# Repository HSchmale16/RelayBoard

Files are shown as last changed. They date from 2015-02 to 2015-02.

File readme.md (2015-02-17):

# Relay Board

**THESE DESIGNS ARE NO WHERE NEAR DONE.**

These are designs for a 32 Channel Relay Board that can be driven with
small microcontrollers, such as the Arduino and the BeagleBone.
The included designs are for KiCad.

These designs are provided with **NO WARRANTY WHATSOEVER**. No liability
is assumed by the designer of these circuits.

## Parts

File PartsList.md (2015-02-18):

# Parts List

* Relays - SPDT
    * TE Connectivity 1461069-5
    * MFR Part No. 1461069-5
    * http://www.digikey.com/product-detail/en/1461069-5/PB1321-ND/3318145
    * $ 1.0156 @ QTY 32
* Diode - 1N4007
    * http://www.digikey.com/product-detail/en/1N4007-TP/1N4007-TPMSCT-ND/773694
    * $ 0.0900 @ QTY 32
* Terminal Block - 3 Connections Screw Type
    * http://www.digikey.com/product-detail/en/OSTTE030161/ED2636-ND/614585
    * $ 0.6000 @ QTY 32
* Transistors - 2N2222
    * http://www.digikey.com/product-detail/en/2N2222/2N2222CS-ND/4806844
    * $ 1.6000 @ QTY 32
* Resistors - 1K ohms
    * http://www.digikey.com/product-detail/en/CFR-25JB-52-1K/1.0KQBK-ND/96
    * $0.04400 @ QTY 32
* Copper Clad Board - 12" x 12"
    * http://www.digikey.com/product-detail/en/555/473-1007-ND/559707
    * $ 22.4200 @ QTY 01

# Notes
Free Shipping: http://dangerousprototypes.com/2011/05/19/free-digikey-shipping-tip/

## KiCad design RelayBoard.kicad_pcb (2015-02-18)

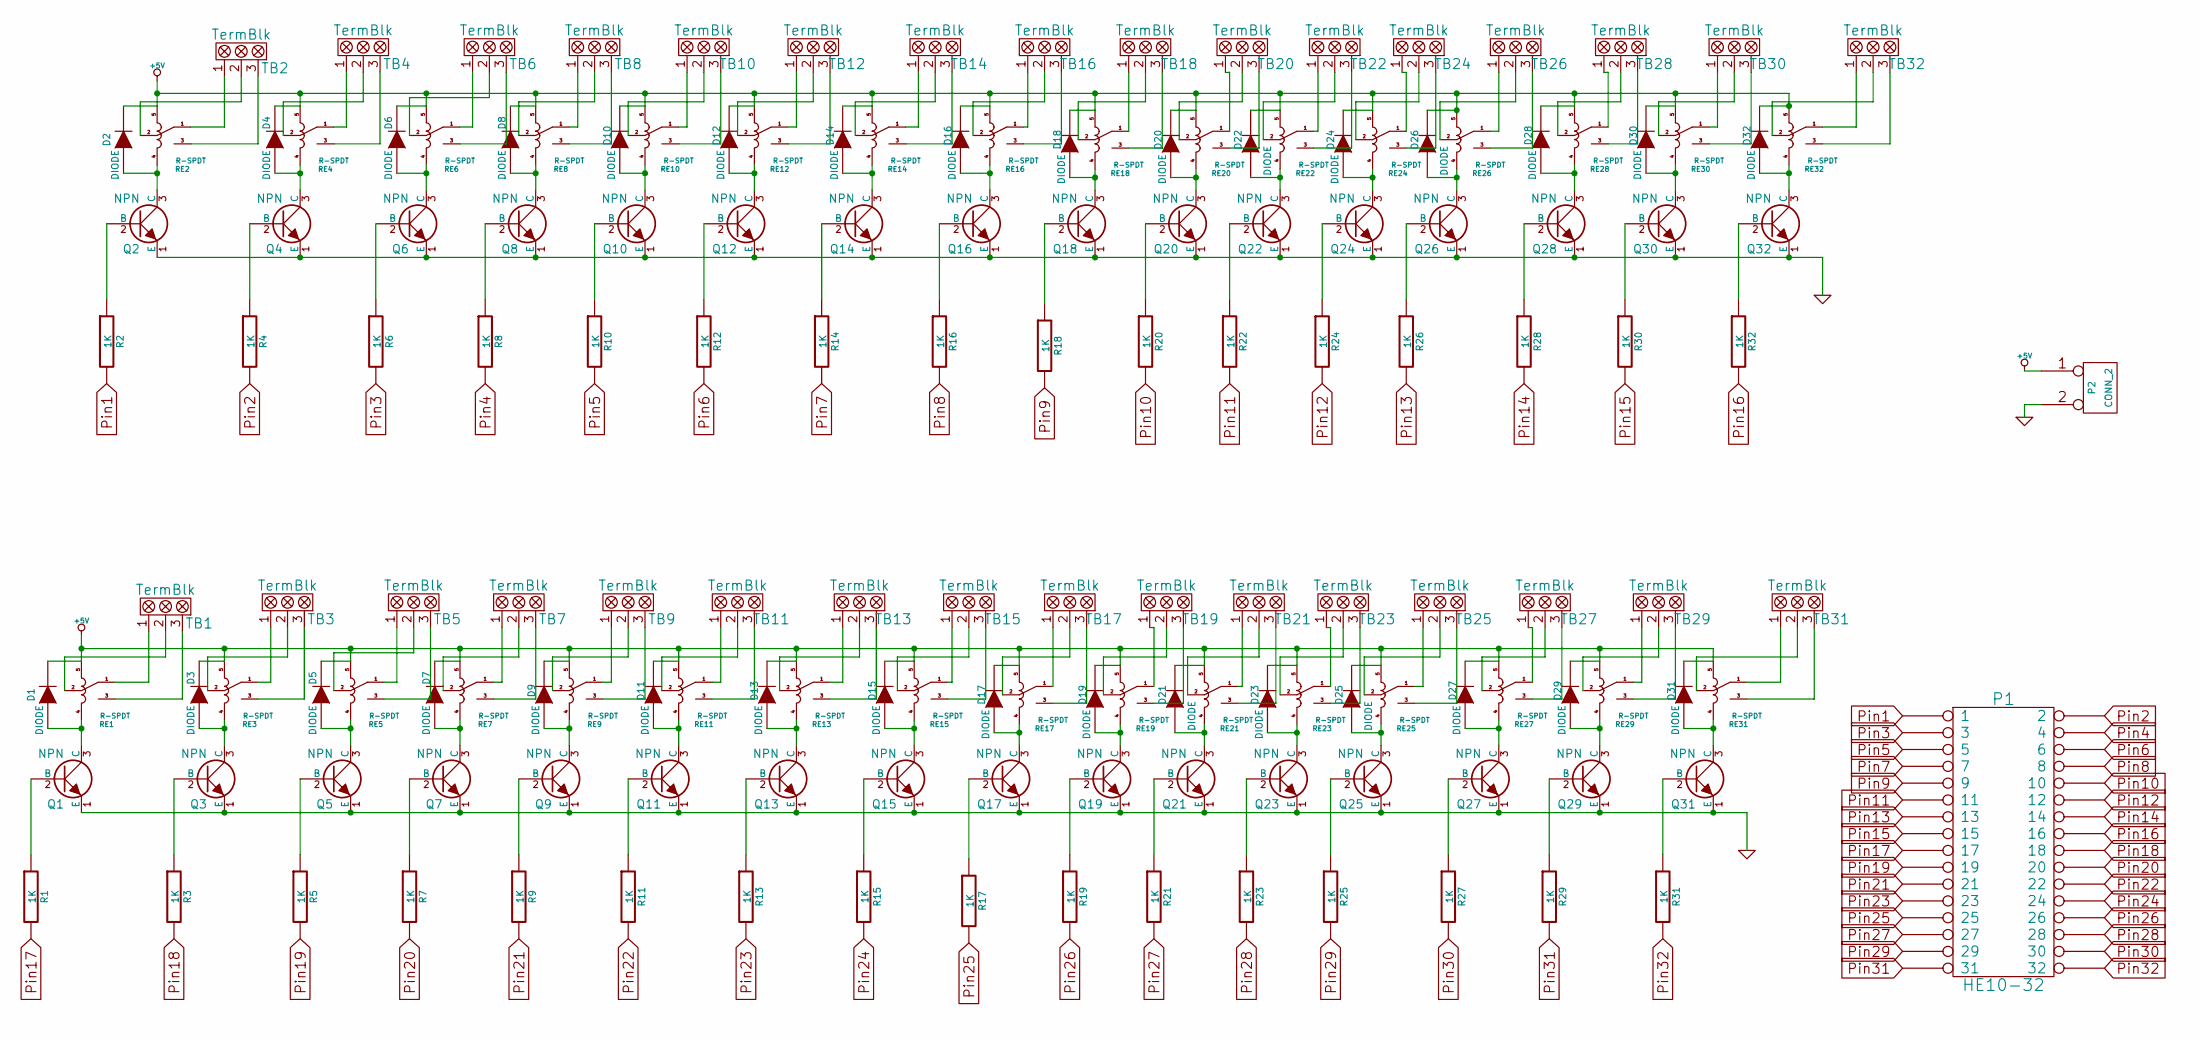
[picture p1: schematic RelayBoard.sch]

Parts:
D1, D2, D3, D4, D5, D6, D7, D8, D9, D10, D11, D12, D13, D14, D15, D16, D17, D18, D19, D20, D21, D22, D23, D24, D25, D26, D27, D28, D29, D30, D31, D32: DIODE
P1: HE10-32
P2: CONN_2
Q1, Q2, Q3, Q4, Q5, Q6, Q7, Q8, Q9, Q10, Q11, Q12, Q13, Q14, Q15, Q16, Q17, Q18, Q19, Q20, Q21, Q22, Q23, Q24, Q25, Q26, Q27, Q28, Q29, Q30, Q31, Q32: NPN
R1, R2, R3, R4, R5, R6, R7, R8, R9, R10, R11, R12, R13, R14, R15, R16, R17, R18, R19, R20, R21, R22, R23, R24, R25, R26, R27, R28, R29, R30, R31, R32: 1K
RE1, RE2, RE3, RE4, RE5, RE6, RE7, RE8, RE9, RE10, RE11, RE12, RE13, RE14, RE15, RE16, RE17, RE18, RE19, RE20, RE21, RE22, RE23, RE24, RE25, RE26, RE27, RE28, RE29, RE30, RE31, RE32: R-SPDT
TB1, TB2, TB3, TB4, TB5, TB6, TB7, TB8, TB9, TB10, TB11, TB12, TB13, TB14, TB15, TB16, TB17, TB18, TB19, TB20, TB21, TB22, TB23, TB24, TB25, TB26, TB27, TB28, TB29, TB30, TB31, TB32: TermBlk

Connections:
+5V: D1.2 (K), D2.2 (K), D3.2 (K), D4.2 (K), D5.2 (K), D6.2 (K), D7.2 (K), D8.2 (K), D9.2 (K), D10.2 (K), D11.2 (K), D12.2 (K), D13.2 (K), D14.2 (K), D15.2 (K), D16.2 (K), D17.2 (K), D18.2 (K), D19.2 (K), D20.2 (K), D21.2 (K), D22.2 (K), D23.2 (K), D24.2 (K), D25.2 (K), D26.2 (K), D27.2 (K), D28.2 (K), D29.2 (K), D30.2 (K), D31.2 (K), D32.2 (K), P2.1, RE1.5, RE2.5, RE3.5, RE4.5, RE5.5, RE6.5, RE7.5, RE8.5, RE9.5, RE10.5, RE11.5, RE12.5, RE13.5, RE14.5, RE15.5, RE16.5, RE17.5, RE18.5, RE19.5, RE20.5, RE21.5, RE22.5, RE23.5, RE24.5, RE25.5, RE26.5, RE27.5, RE28.5, RE29.5, RE30.5, RE31.5, RE32.5
GND: P2.2 (PM), Q1.1 (E), Q2.1 (E), Q3.1 (E), Q4.1 (E), Q5.1 (E), Q6.1 (E), Q7.1 (E), Q8.1 (E), Q9.1 (E), Q10.1 (E), Q11.1 (E), Q12.1 (E), Q13.1 (E), Q14.1 (E), Q15.1 (E), Q16.1 (E), Q17.1 (E), Q18.1 (E), Q19.1 (E), Q20.1 (E), Q21.1 (E), Q22.1 (E), Q23.1 (E), Q24.1 (E), Q25.1 (E), Q26.1 (E), Q27.1 (E), Q28.1 (E), Q29.1 (E), Q30.1 (E), Q31.1 (E), Q32.1 (E)
unnamed: D1.1 (A), Q1.3 (C), RE1.4
unnamed: D2.1 (A), Q2.3 (C), RE2.4
unnamed: D3.1 (A), Q3.3 (C), RE3.4
unnamed: D4.1 (A), Q4.3 (C), RE4.4
unnamed: D5.1 (A), Q5.3 (C), RE5.4
unnamed: D6.1 (A), Q6.3 (C), RE6.4
unnamed: D7.1 (A), Q7.3 (C), RE7.4
unnamed: D8.1 (A), Q8.3 (C), RE8.4
unnamed: D9.1 (A), Q9.3 (C), RE9.4
unnamed: D10.1 (A), Q10.3 (C), RE10.4
unnamed: D11.1 (A), Q11.3 (C), RE11.4
unnamed: D12.1 (A), Q12.3 (C), RE12.4
unnamed: D13.1 (A), Q13.3 (C), RE13.4
unnamed: D14.1 (A), Q14.3 (C), RE14.4
unnamed: D15.1 (A), Q15.3 (C), RE15.4
unnamed: D16.1 (A), Q16.3 (C), RE16.4
unnamed: D17.1 (A), Q17.3 (C), RE17.4
unnamed: D18.1 (A), Q18.3 (C), RE18.4
unnamed: D19.1 (A), Q19.3 (C), RE19.4
unnamed: D20.1 (A), Q20.3 (C), RE20.4
unnamed: D21.1 (A), Q21.3 (C), RE21.4
unnamed: D22.1 (A), Q22.3 (C), RE22.4
unnamed: D23.1 (A), Q23.3 (C), RE23.4
unnamed: D24.1 (A), Q24.3 (C), RE24.4
unnamed: D25.1 (A), Q25.3 (C), RE25.4
unnamed: D26.1 (A), Q26.3 (C), RE26.4
unnamed: D27.1 (A), Q27.3 (C), RE27.4
unnamed: D28.1 (A), Q28.3 (C), RE28.4
unnamed: D29.1 (A), Q29.3 (C), RE29.4
unnamed: D30.1 (A), Q30.3 (C), RE30.4
unnamed: D31.1 (A), Q31.3 (C), RE31.4
unnamed: D32.1 (A), Q32.3 (C), RE32.4
unnamed: Q1.2 (B), R1.1
unnamed: Q2.2 (B), R2.1
unnamed: Q3.2 (B), R3.1
unnamed: Q4.2 (B), R4.1
unnamed: Q5.2 (B), R5.1
unnamed: Q6.2 (B), R6.1
unnamed: Q7.2 (B), R7.1
unnamed: Q8.2 (B), R8.1
unnamed: Q9.2 (B), R9.1
unnamed: Q10.2 (B), R10.1
unnamed: Q11.2 (B), R11.1
unnamed: Q12.2 (B), R12.1
unnamed: Q13.2 (B), R13.1
unnamed: Q14.2 (B), R14.1
unnamed: Q15.2 (B), R15.1
unnamed: Q16.2 (B), R16.1
unnamed: Q17.2 (B), R17.1
unnamed: Q18.2 (B), R18.1
unnamed: Q19.2 (B), R19.1
unnamed: Q20.2 (B), R20.1
unnamed: Q21.2 (B), R21.1
unnamed: Q22.2 (B), R22.1
unnamed: Q23.2 (B), R23.1
unnamed: Q24.2 (B), R24.1
unnamed: Q25.2 (B), R25.1
unnamed: Q26.2 (B), R26.1
unnamed: Q27.2 (B), R27.1
unnamed: Q28.2 (B), R28.1
unnamed: Q29.2 (B), R29.1
unnamed: Q30.2 (B), R30.1
unnamed: Q31.2 (B), R31.1
unnamed: Q32.2 (B), R32.1
unnamed: RE1.1, TB1.1
unnamed: RE1.2, TB1.2
unnamed: RE1.3, TB1.3
unnamed: RE2.1, TB2.1
unnamed: RE2.2, TB2.2
unnamed: RE2.3, TB2.3
unnamed: RE3.1, TB3.1
unnamed: RE3.2, TB3.2
unnamed: RE3.3, TB3.3
unnamed: RE4.1, TB4.1
unnamed: RE4.2, TB4.2
unnamed: RE4.3, TB4.3
unnamed: RE5.1, TB5.1
unnamed: RE5.2, TB5.2
unnamed: RE5.3, TB5.3
unnamed: RE6.1, TB6.1
unnamed: RE6.2, TB6.2
unnamed: RE6.3, TB6.3
unnamed: RE7.1, TB7.1
unnamed: RE7.2, TB7.2
unnamed: RE7.3, TB7.3
unnamed: RE8.1, TB8.1
unnamed: RE8.2, TB8.2
unnamed: RE8.3, TB8.3
unnamed: RE9.1, TB9.1
unnamed: RE9.2, TB9.2
unnamed: RE9.3, TB9.3
unnamed: RE10.1, TB10.1
unnamed: RE10.2, TB10.2
unnamed: RE10.3, TB10.3
unnamed: RE11.1, TB11.1
unnamed: RE11.2, TB11.2
unnamed: RE11.3, TB11.3
unnamed: RE12.1, TB12.1
unnamed: RE12.2, TB12.2
unnamed: RE12.3, TB12.3
unnamed: RE13.1, TB13.1
unnamed: RE13.2, TB13.2
unnamed: RE13.3, TB13.3
unnamed: RE14.1, TB14.1
unnamed: RE14.2, TB14.2
unnamed: RE14.3, TB14.3
unnamed: RE15.1, TB15.1
unnamed: RE15.2, TB15.2
unnamed: RE15.3, TB15.3
unnamed: RE16.1, TB16.1
unnamed: RE16.2, TB16.2
unnamed: RE16.3, TB16.3
unnamed: RE17.1, TB17.1
unnamed: RE17.2, TB17.2
unnamed: RE17.3, TB17.3
unnamed: RE18.1, TB18.1
unnamed: RE18.2, TB18.2
unnamed: RE18.3, TB18.3
unnamed: RE19.1, TB19.1
unnamed: RE19.2, TB19.2
unnamed: RE19.3, TB19.3
unnamed: RE20.1, TB20.1
unnamed: RE20.2, TB20.2
unnamed: RE20.3, TB20.3
unnamed: RE21.1, TB21.1
unnamed: RE21.2, TB21.2
unnamed: RE21.3, TB21.3
unnamed: RE22.1, TB22.1
unnamed: RE22.2, TB22.2
unnamed: RE22.3, TB22.3
unnamed: RE23.1, TB23.1
unnamed: RE23.2, TB23.2
unnamed: RE23.3, TB23.3
unnamed: RE24.1, TB24.1
unnamed: RE24.2, TB24.2
unnamed: RE24.3, TB24.3
unnamed: RE25.1, TB25.1
unnamed: RE25.2, TB25.2
unnamed: RE25.3, TB25.3
unnamed: RE26.1, TB26.1
unnamed: RE26.2, TB26.2
unnamed: RE26.3, TB26.3
unnamed: RE27.1, TB27.1
unnamed: RE27.2, TB27.2
unnamed: RE27.3, TB27.3
unnamed: RE28.1, TB28.1
unnamed: RE28.2, TB28.2
unnamed: RE28.3, TB28.3
unnamed: RE29.1, TB29.1
unnamed: RE29.2, TB29.2
unnamed: RE29.3, TB29.3
unnamed: RE30.1, TB30.1
unnamed: RE30.2, TB30.2
unnamed: RE30.3, TB30.3
unnamed: RE31.1, TB31.1
unnamed: RE31.2, TB31.2
unnamed: RE31.3, TB31.3
unnamed: RE32.1, TB32.1
unnamed: RE32.2, TB32.2
unnamed: RE32.3, TB32.3
Pin1: P1.1, R2.2
Pin2: P1.2, R4.2
Pin3: P1.3, R6.2
Pin4: P1.4, R8.2
Pin5: P1.5, R10.2
Pin6: P1.6, R12.2
Pin7: P1.7, R14.2
Pin8: P1.8, R16.2
Pin9: P1.9, R18.2
Pin10: P1.10, R20.2
Pin11: P1.11, R22.2
Pin12: P1.12, R24.2
Pin13: P1.13, R26.2
Pin14: P1.14, R28.2
Pin15: P1.15, R30.2
Pin16: P1.16, R32.2
Pin17: P1.17, R1.2
Pin18: P1.18, R3.2
Pin19: P1.19, R5.2
Pin20: P1.20, R7.2
Pin21: P1.21, R9.2
Pin22: P1.22, R11.2
Pin23: P1.23, R13.2
Pin24: P1.24, R15.2
Pin25: P1.25, R17.2
Pin26: P1.26, R19.2
Pin27: P1.27, R21.2
Pin28: P1.28, R23.2
Pin29: P1.29, R25.2
Pin30: P1.30, R27.2
Pin31: P1.31, R29.2
Pin32: P1.32, R31.2

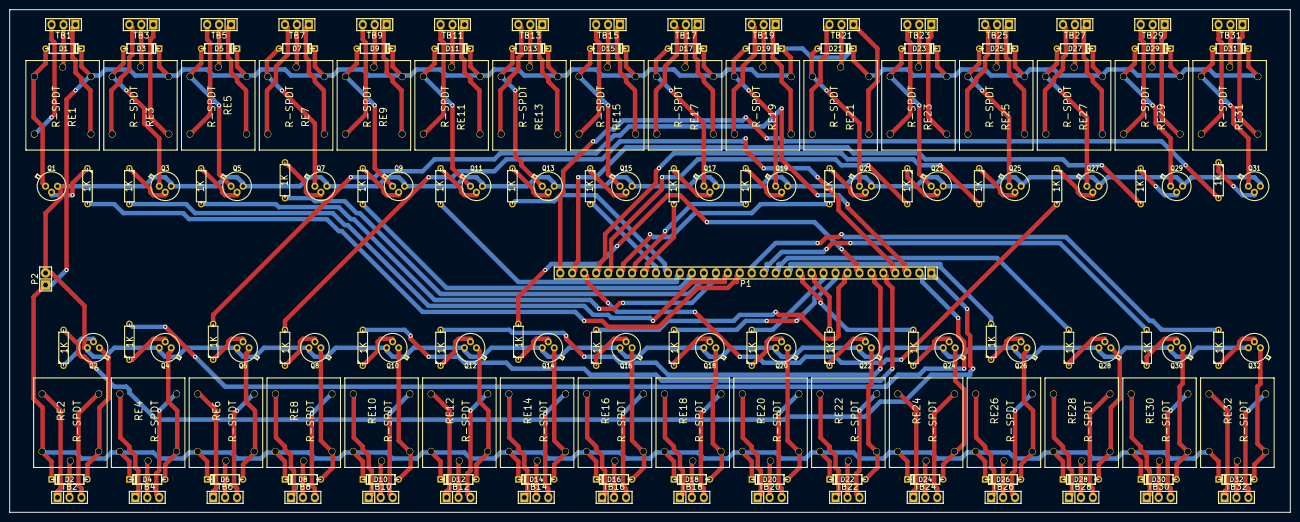
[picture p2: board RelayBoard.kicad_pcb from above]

Board: 2 copper layers, 271.8 x 106.7 mm, 162 parts (0 on the bottom side), 194 nets.

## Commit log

2015-02-16 Inital Commit
    [RelayBoard.sch]
2015-02-16 Added A New Componet to Relay Lib
    * A dioded relay
    [RelayBoard.sch]
2015-02-16 New Componets
    * Added Transisters to Diagram
    * Wired Diagram
    [RelayBoard.sch]
2015-02-16 Connected to GND
    [RelayBoard.sch]
2015-02-16 Terminal Blocks
    [RelayBoard.sch]
2015-02-16 More To The Schematic Than Meets The Eye.
    [RelayBoard.sch]
2015-02-16 End of worktime
    [RelayBoard.sch]
2015-02-17 Finished Pins 1 to 16 connections
    [RelayBoard.sch]
2015-02-17 Finished Pins 17 to 24, they are now connected to the bus
    [RelayBoard.sch]
2015-02-17 Connected Pins 24 to 32, Still need to resolve electric rules errors
    [RelayBoard.sch]
2015-02-17 Finished Schematic
    * Updated Relay Lib Componet Descriptions
    * Generated A NetList
    [RelayBoard.sch]
2015-02-17 Added A PCB File
    [RelayBoard.kicad_pcb]
2015-02-17 Created A Custom Footprint for the relays
    * Finished Part Selection in CVPCB
    * Custom FootPrint Lib
2015-02-17 Started laying out PCB
    [RelayBoard.kicad_pcb]
2015-02-17 Update
    * Updated Readme with a warning.
    * The schematic is nowhere near done as I forgot to include diodes to
    protect against the feedback from relays turning on and off.
    [RelayBoard.kicad_pcb, RelayBoard.sch]
2015-02-17 Finished Schematic
    * The schematic now has diodes where needed
    * Parts are associated as needed
    [RelayBoard.sch]
2015-02-18 Placed Most of the relays on the PCB
    [RelayBoard.kicad_pcb]
2015-02-18 Placed all of the relays on the PCB.
    [RelayBoard.kicad_pcb]
2015-02-18 Placed all of the terminal blocks on the PCB.
    [RelayBoard.kicad_pcb]
2015-02-18 Did a bunch to the PCB Layout
    * Diode Placement
    * Tracks
    * Commenting
    [RelayBoard.kicad_pcb]
2015-02-18 Changed The Pin headers
    * Changed Pin Headers
    * Placed Most of the resistors on the board
    [RelayBoard.kicad_pcb]
2015-02-18 Finished Placing all parts on PCB
    It's time to route the board
    [RelayBoard.kicad_pcb]
2015-02-18 Changed the footprint of primary input header from 2x16 to 1x32 Due to routing concerns
    [RelayBoard.kicad_pcb]
2015-02-18 Just finished routing
    Autoroute is amazing!
    [RelayBoard.kicad_pcb]
2015-02-18 Stuff
    * Dimension Drawing
    * PCB Edges are now included
    [RelayBoard.kicad_pcb]
